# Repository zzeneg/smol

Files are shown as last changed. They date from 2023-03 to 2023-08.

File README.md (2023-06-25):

# Smol

Small and cheap low profile split keyboard with 36 keys using RP2040 Zero microcontrollers.

## Features

- 36 keys
- low profile choc switches with hotswap and choc spacing
- per-key RGB matrix
- Waveshare RP2040 Zero controller
- QMK firmware
- TRRS connection between splits (can use USB-C instead but not recommended, too low for many cables)
- Panasonic EVQWGD001 roller encoder (left side only) or EC11 rotary encoder (both sides)

## Photos

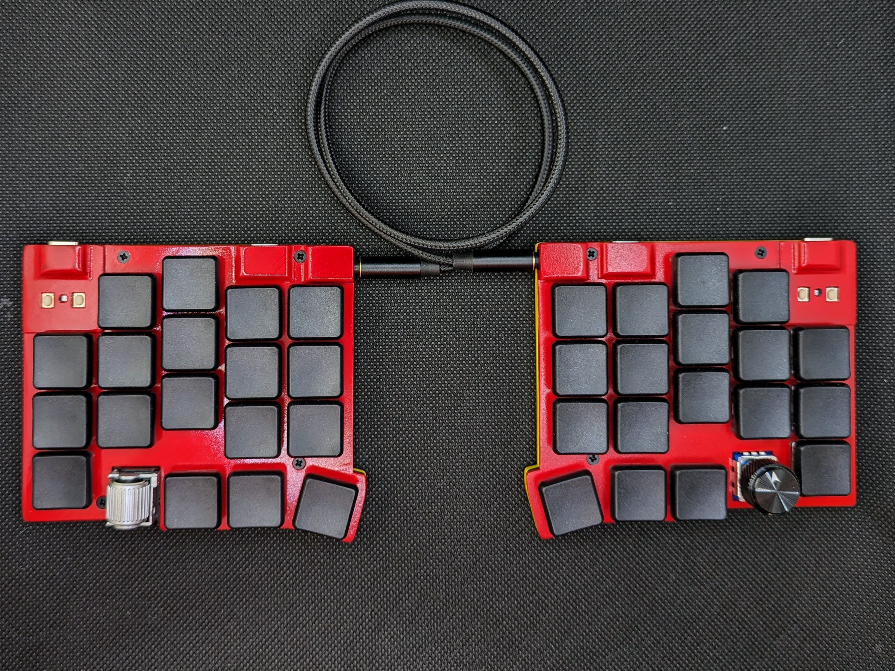
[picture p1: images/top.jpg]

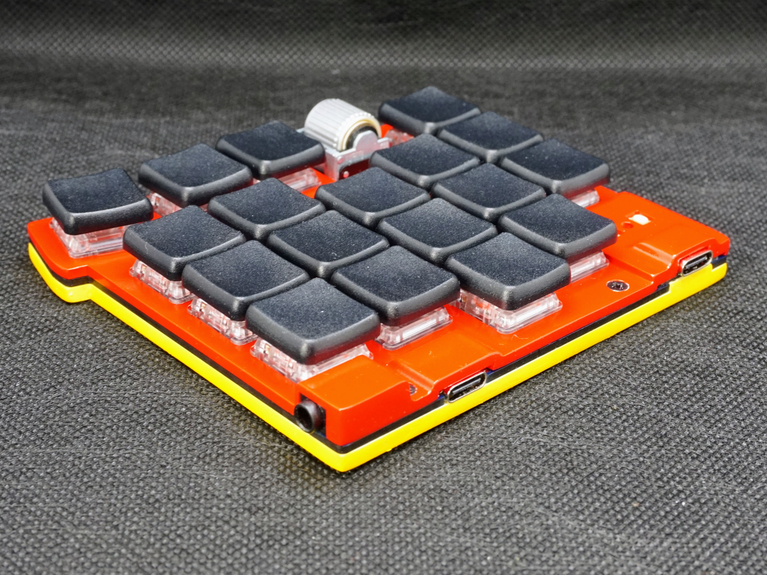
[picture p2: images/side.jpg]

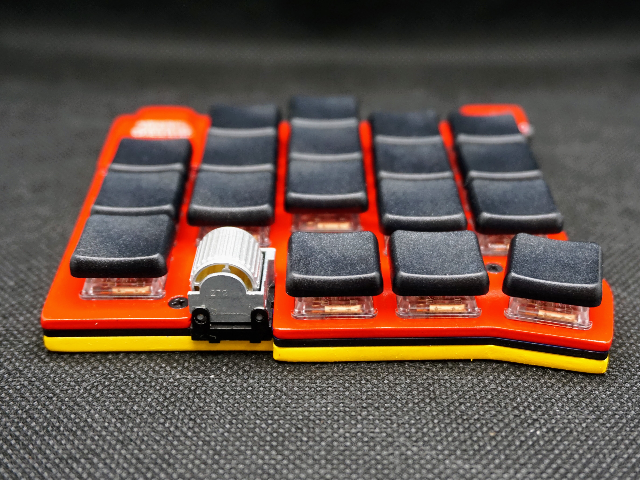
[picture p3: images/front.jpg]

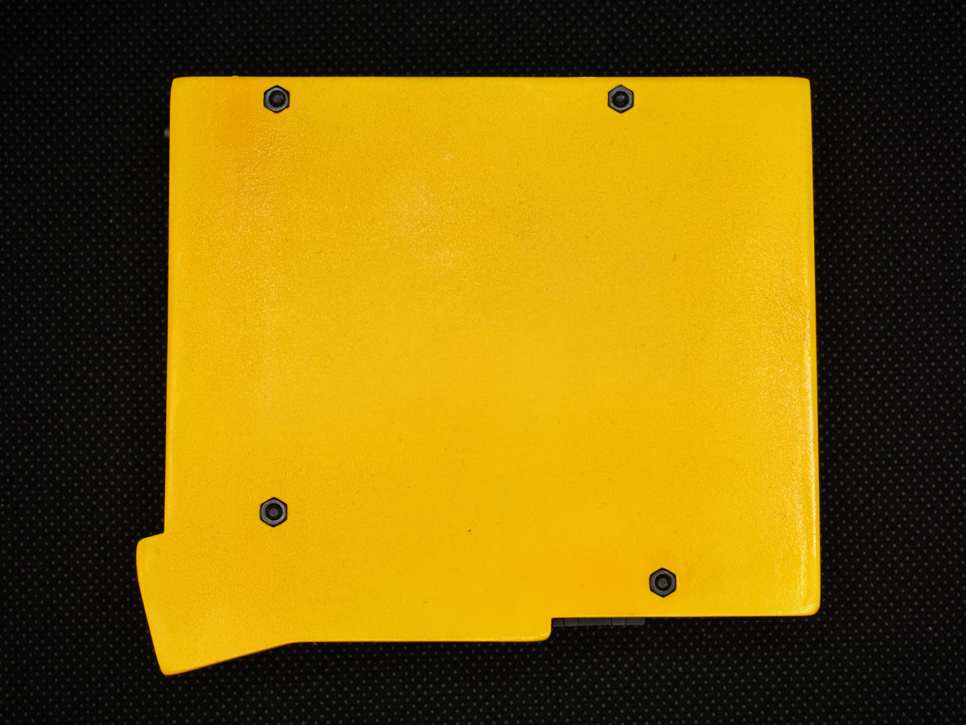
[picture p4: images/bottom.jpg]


## Gerber files

- [PCB](gerbers/pcb.zip)

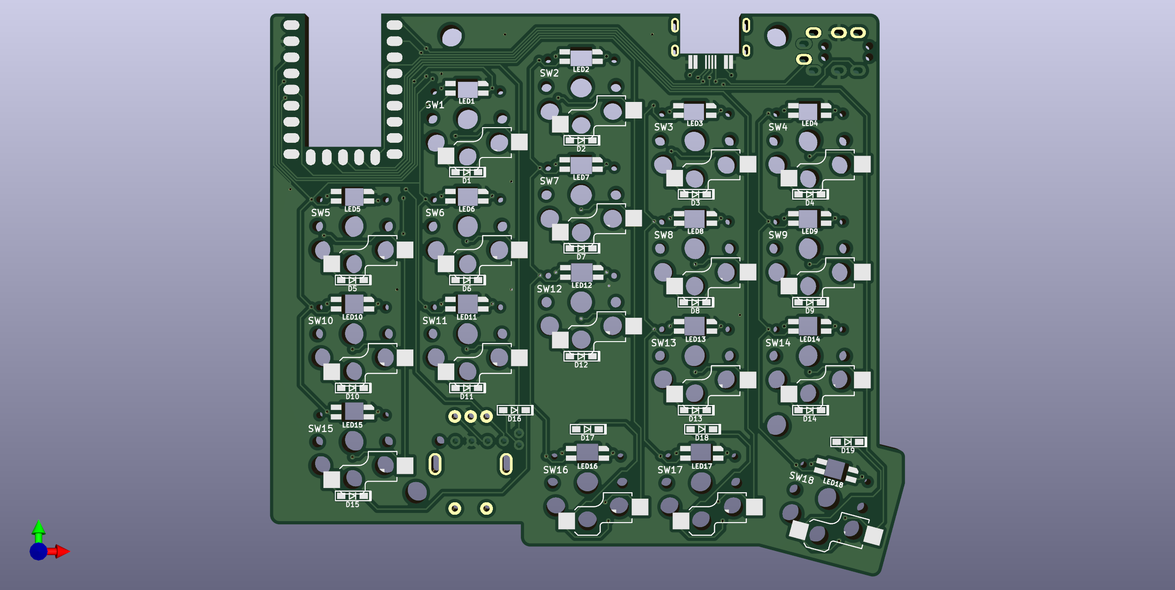
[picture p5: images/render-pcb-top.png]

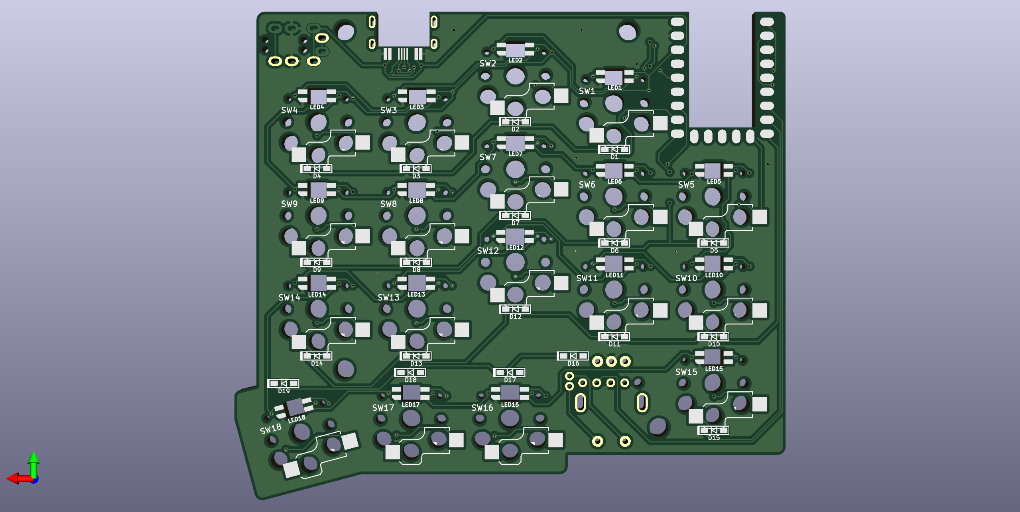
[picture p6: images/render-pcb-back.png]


## Case files

In [STL folder](./stl/) - files for left/right parts. Left also has a version for roller encoder (make sure to order both top and bottom with roller).

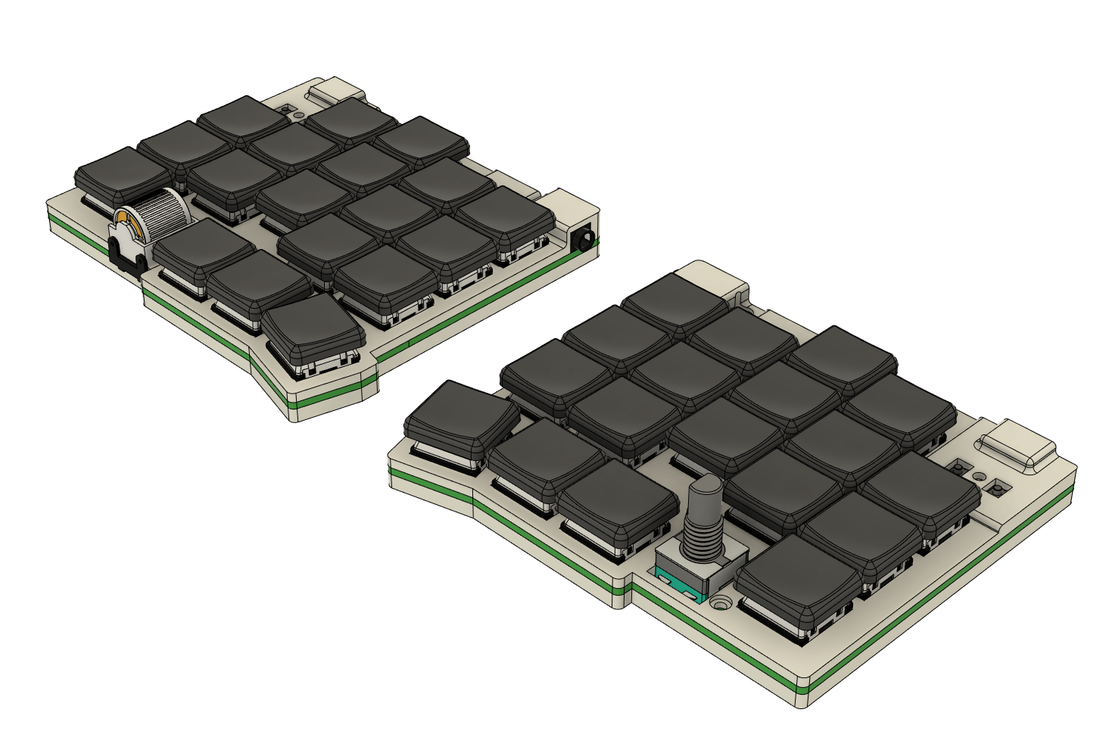
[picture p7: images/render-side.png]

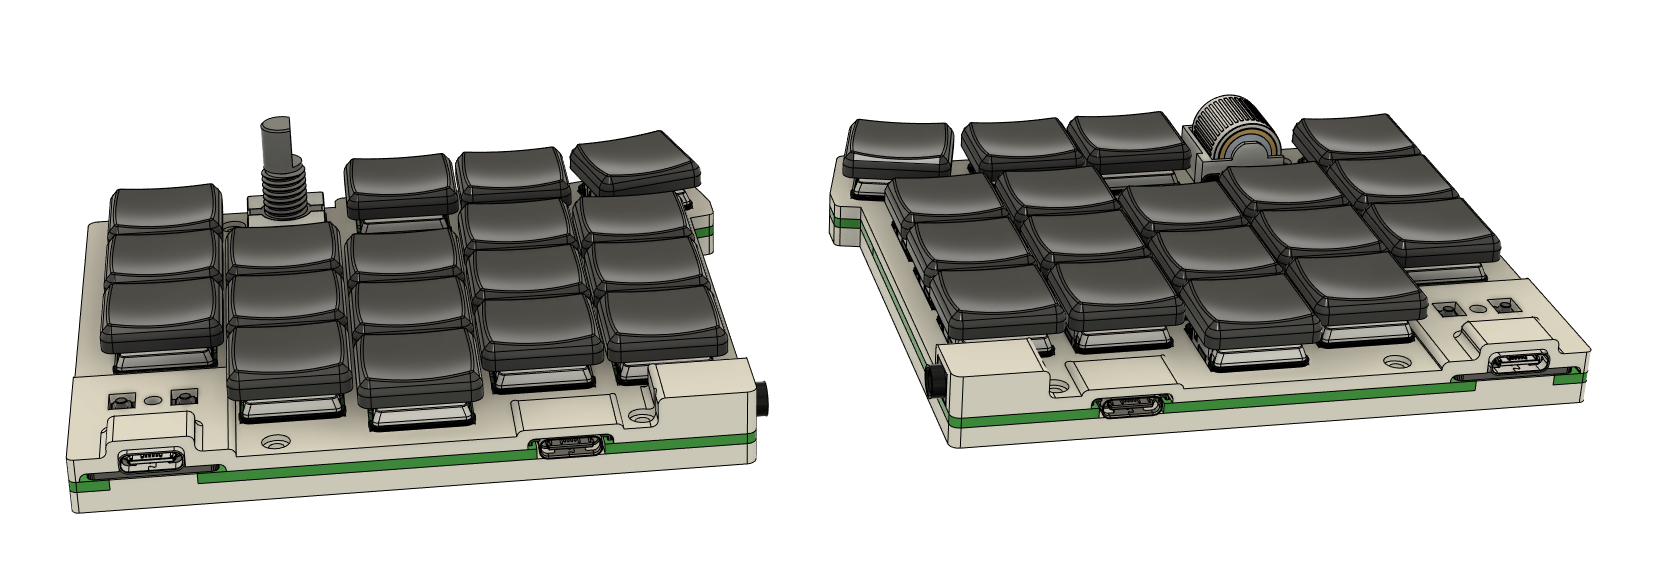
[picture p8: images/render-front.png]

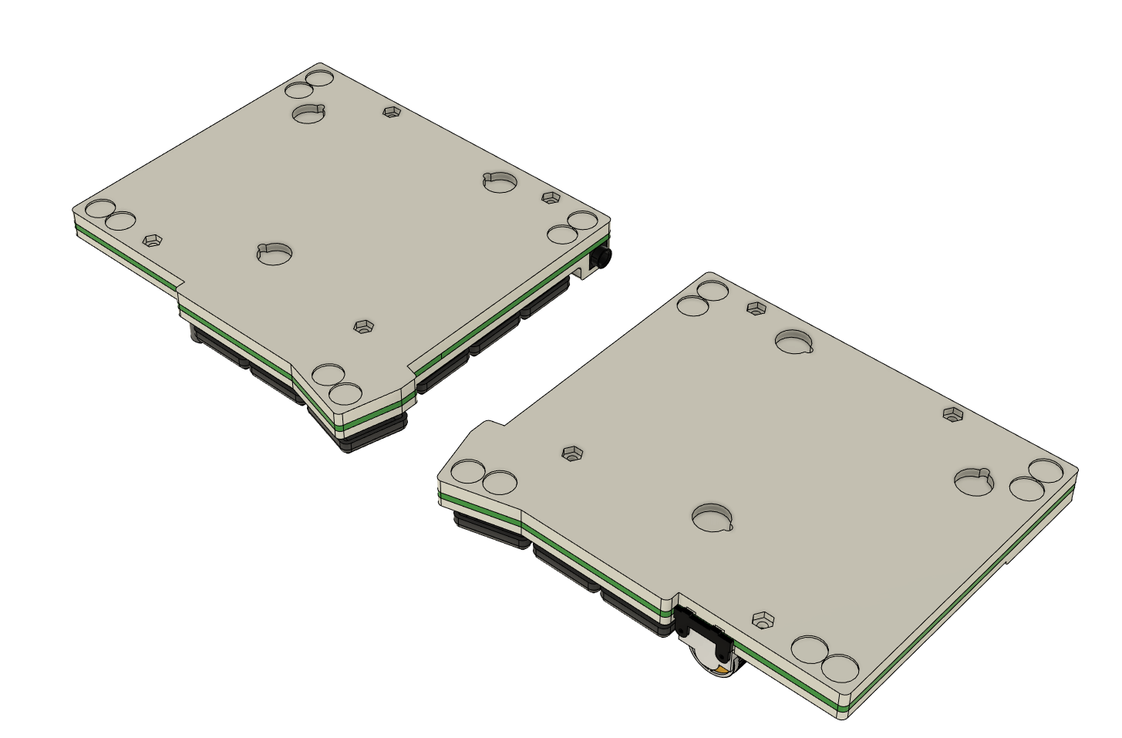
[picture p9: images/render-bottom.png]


## Bill of materials

_Prices for EU with taxes and shipping_

Total cost with required parts: **$42**

- PCBs - $6 (JLCPCB)
- Case (4 parts) - $13 (JLCPCB, white resin)
- 2 Waveshare [RP2040 Zero](https://www.aliexpress.com/item/3256804090654134.html) MCUs - $8.5
- 36 [SMD SOD-123 1N4148](https://www.aliexpress.com/item/1005002882901030.html) diodes - $2
- 1 or 2 [EC11/12 rotary encoder](https://www.aliexpress.com/item/33006686909.html) with [knob](https://www.aliexpress.com/item/1005003425428192.html) - $5
- [Panasonic EVQWGD001 roller encoder](https://www.aliexpress.com/item/32990950196.html) - $9, optional
- 6mm M2 [screws with flat head](https://www.aliexpress.com/item/4001248931159.html) and [nuts](https://www.aliexpress.com/item/1005001412230125.html) - $4
- [TRRS PJ-320A](https://www.aliexpress.com/item/4000661212458.html) connectors - $1.5
- [TRRS cable](https://www.aliexpress.com/item/1005003676559658.html) - $2
- [RGB LEDs](https://www.aliexpress.com/item/1005003636607308.html) - $8.5, optional

## Firmware

QMK:

- [source code](https://github.com/zzeneg/qmk_firmware/tree/feature/smol/keyboards/smol)
- [pre-compiled file](./firmware/qmk/smol_zzeneg.uf2)

Vial:

- [source code](https://github.com/zzeneg/vial-qmk/tree/feature/smol/keyboards/smol)
- [pre-compiled file](./firmware/vial/smol_vial.uf2)

## Changelog

- 2023-06-25 - new case with magnet and feet holes, new Fusion 360 project with design history

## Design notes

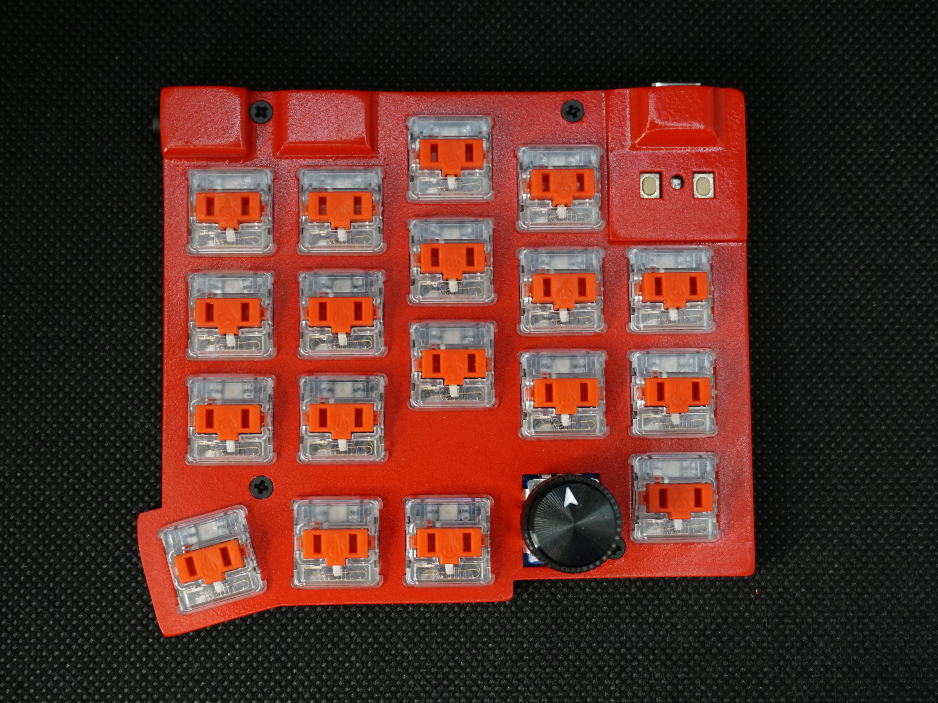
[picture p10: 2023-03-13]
images/naked.jpg

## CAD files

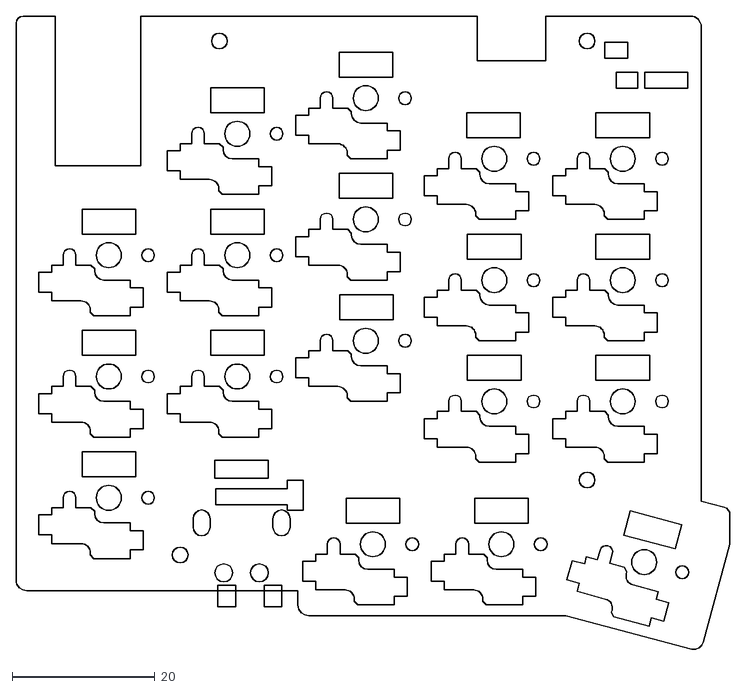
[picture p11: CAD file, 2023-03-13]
case/bottom-left.dxf
100.0 x 88.8

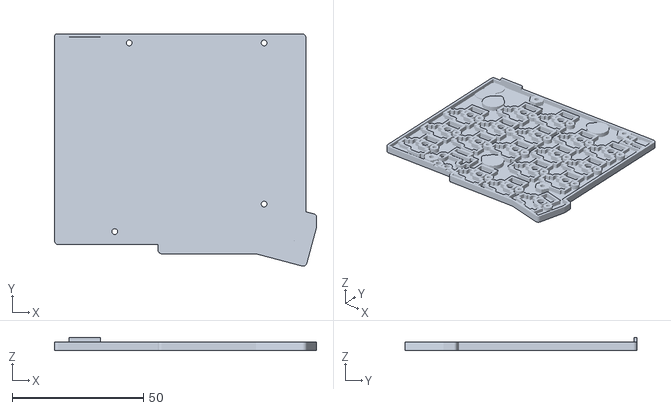
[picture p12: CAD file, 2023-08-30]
stl/bottom_case v14_left-roller.stl
100.0 x 88.7 x 4.80

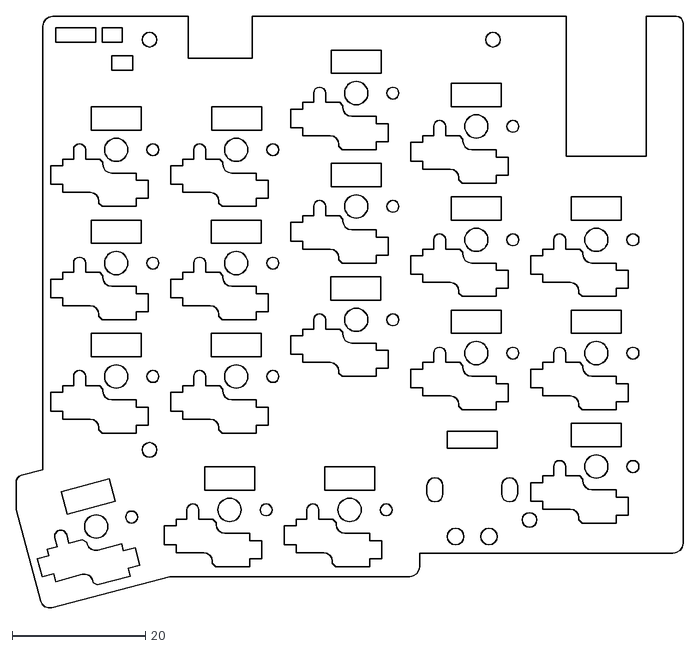
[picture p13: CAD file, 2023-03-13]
case/bottom-right.dxf
100.0 x 88.8

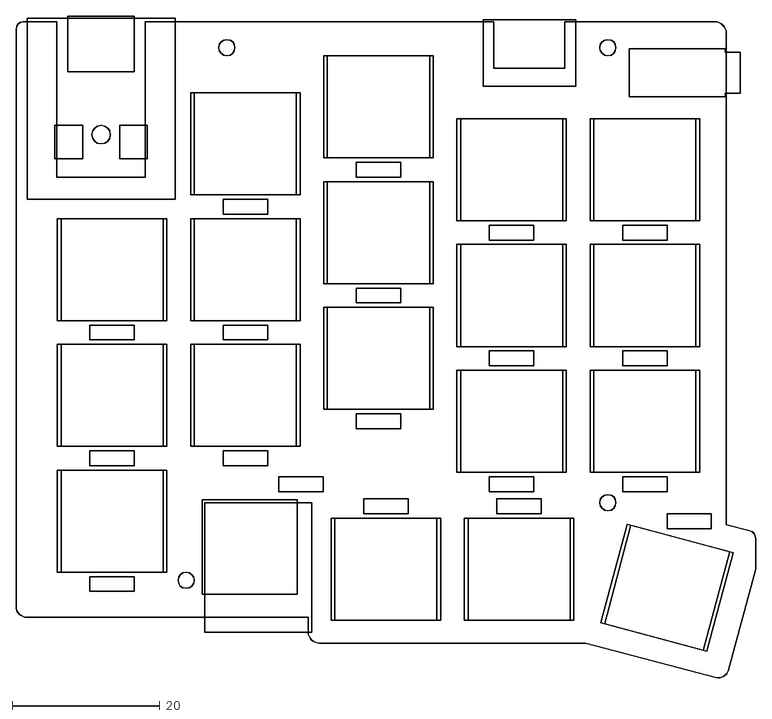
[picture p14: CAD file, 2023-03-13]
case/top-left.dxf
100.0 x 89.6

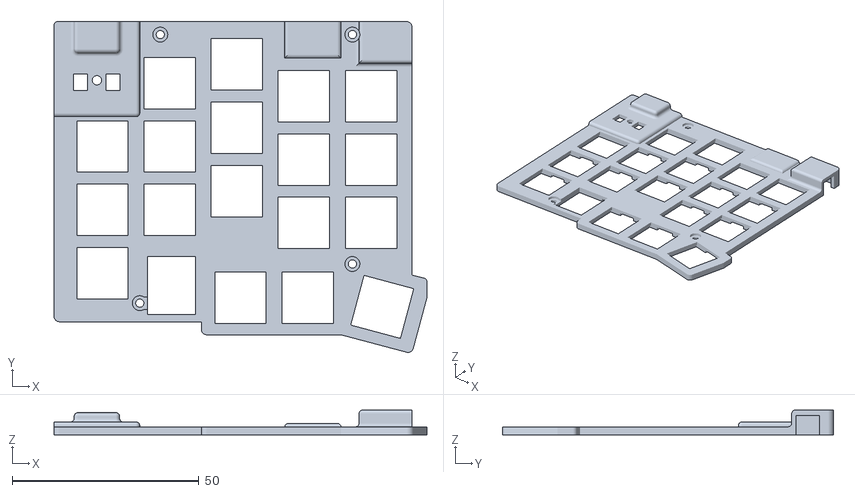
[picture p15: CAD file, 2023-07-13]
stl/top_case v12_left.stl
100.0 x 88.7 x 6.70

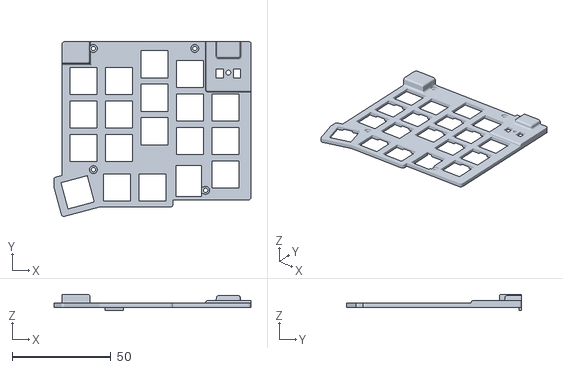
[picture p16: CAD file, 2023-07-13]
stl/top_case v12_right-no-usb.stl
100.0 x 88.7 x 8.30

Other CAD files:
stl/bottom_case v14_left.stl
stl/bottom_case v14_right.stl
stl/top_case v12_right.stl
stl/top_case v12_left-roller-no-usb.stl
stl/top_case v12_left-roller.stl
stl/top_case v12_left-no-usb.stl

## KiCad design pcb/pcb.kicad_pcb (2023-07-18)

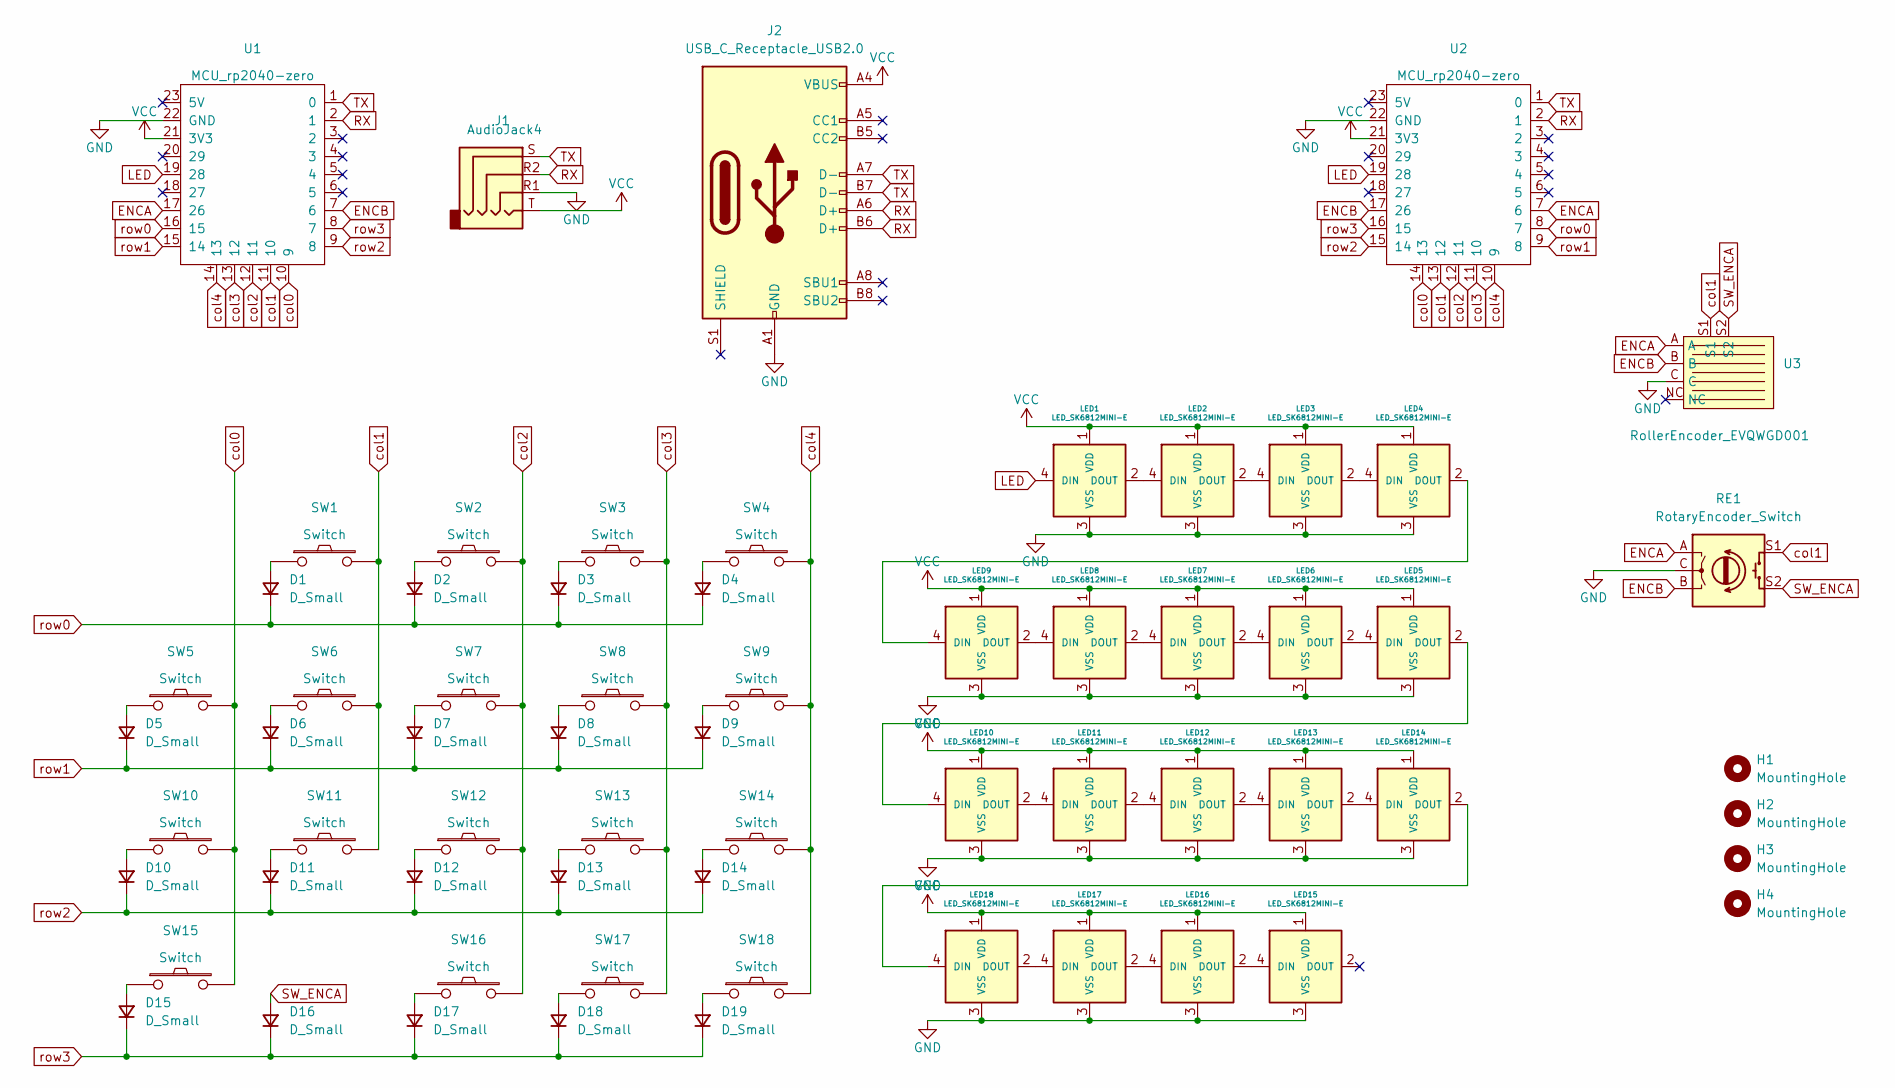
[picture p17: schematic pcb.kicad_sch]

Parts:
D1, D2, D3, D4, D5, D6, D7, D8, D9, D10, D11, D12, D13, D14, D15, D16, D17, D18, D19: D_Small; Diode_1N4148-SOD123-reversible-flip3d
H1, H2, H3, H4: MountingHole; Hole_M2-spacer
J1: AudioJack4; Connector_TRRS-reversible
J2: USB_C_Receptacle_USB2.0; Connector_USB-C-mid-mount-ali-reversible-data
LED1, LED2, LED3, LED4, LED5, LED6, LED7, LED8, LED9, LED10, LED11, LED12, LED13, LED14, LED15, LED16, LED17, LED18: LED_SK6812MINI-E; LED_SK6812-MINI-E-reversible
RE1: RotaryEncoder_Switch; RotaryEncoder_EC11-reversible
SW1, SW2, SW3, SW4, SW5, SW6, SW7, SW8, SW9, SW10, SW11, SW12, SW13, SW14, SW15, SW16, SW17, SW18: Switch; Switch_ChocV1-hotswap-reversible
U1, U2: MCU_rp2040-zero; MCU_rp2040-zero-smd
U3: RollerEncoder_EVQWGD001; RotaryEncoder_EVQWGD001

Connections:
ENCA: RE1.A, U1.17 (26), U2.7 (6), U3.A
ENCB: RE1.B, U1.7 (6), U2.17 (26), U3.B
GND: J1.R1, J2.A1 (GND), J2.A12 (GND), J2.B1 (GND), J2.B12 (GND), LED1.3 (VSS), LED2.3 (VSS), LED3.3 (VSS), LED4.3 (VSS), LED5.3 (VSS), LED6.3 (VSS), LED7.3 (VSS), LED8.3 (VSS), LED9.3 (VSS), LED10.3 (VSS), LED11.3 (VSS), LED12.3 (VSS), LED13.3 (VSS), LED14.3 (VSS), LED15.3 (VSS), LED16.3 (VSS), LED17.3 (VSS), LED18.3 (VSS), RE1.C, U1.22 (GND), U2.22 (GND), U3.C
LED: LED1.4 (DIN), U1.19 (28), U2.19 (28)
unnamed: D1.2 (A), SW1.1
unnamed: D2.2 (A), SW2.1
unnamed: D3.2 (A), SW3.1
unnamed: D4.2 (A), SW4.1
unnamed: D5.2 (A), SW5.1
unnamed: D6.2 (A), SW6.1
unnamed: D7.2 (A), SW7.1
unnamed: D8.2 (A), SW8.1
unnamed: D9.2 (A), SW9.1
unnamed: D10.2 (A), SW10.1
unnamed: D11.2 (A), SW11.1
unnamed: D12.2 (A), SW12.1
unnamed: D13.2 (A), SW13.1
unnamed: D14.2 (A), SW14.1
unnamed: D15.2 (A), SW15.1
unnamed: D17.2 (A), SW16.1
unnamed: D18.2 (A), SW17.1
unnamed: D19.2 (A), SW18.1
unnamed: LED1.2 (DOUT), LED2.4 (DIN)
unnamed: LED2.2 (DOUT), LED3.4 (DIN)
unnamed: LED3.2 (DOUT), LED4.4 (DIN)
unnamed: LED4.2 (DOUT), LED9.4 (DIN)
unnamed: LED5.4 (DIN), LED6.2 (DOUT)
unnamed: LED6.4 (DIN), LED7.2 (DOUT)
unnamed: LED7.4 (DIN), LED8.2 (DOUT)
unnamed: LED8.4 (DIN), LED9.2 (DOUT)
unnamed: LED10.2 (DOUT), LED11.4 (DIN)
unnamed: LED5.2 (DOUT), LED10.4 (DIN)
unnamed: LED11.2 (DOUT), LED12.4 (DIN)
unnamed: LED12.2 (DOUT), LED13.4 (DIN)
unnamed: LED13.2 (DOUT), LED14.4 (DIN)
unnamed: LED14.2 (DOUT), LED18.4 (DIN)
unnamed: LED15.4 (DIN), LED16.2 (DOUT)
unnamed: LED16.4 (DIN), LED17.2 (DOUT)
unnamed: LED17.4 (DIN), LED18.2 (DOUT)
RX: J1.R2, J2.A6 (D+), J2.B6 (D+), U1.2 (1), U2.2 (1)
SW_ENCA: D16.2 (A), RE1.S2, U3.S2
TX: J1.S, J2.A7 (D-), J2.B7 (D-), U1.1 (0), U2.1 (0)
VCC: J1.T, J2.A4 (VBUS), J2.A9 (VBUS), J2.B4 (VBUS), J2.B9 (VBUS), LED1.1 (VDD), LED2.1 (VDD), LED3.1 (VDD), LED4.1 (VDD), LED5.1 (VDD), LED6.1 (VDD), LED7.1 (VDD), LED8.1 (VDD), LED9.1 (VDD), LED10.1 (VDD), LED11.1 (VDD), LED12.1 (VDD), LED13.1 (VDD), LED14.1 (VDD), LED15.1 (VDD), LED16.1 (VDD), LED17.1 (VDD), LED18.1 (VDD), U1.21 (3V3), U2.21 (3V3)
col0: SW5.2, SW10.2, SW15.2, U1.10 (9), U2.14 (13)
col1: RE1.S1, SW1.2, SW6.2, SW11.2, U1.11 (10), U2.13 (12), U3.S1
col2: SW2.2, SW7.2, SW12.2, SW16.2, U1.12 (11), U2.12 (11)
col3: SW3.2, SW8.2, SW13.2, SW17.2, U1.13 (12), U2.11 (10)
col4: SW4.2, SW9.2, SW14.2, SW18.2, U1.14 (13), U2.10 (9)
row0: D1.1 (K), D2.1 (K), D3.1 (K), D4.1 (K), U1.16 (15), U2.8 (7)
row1: D5.1 (K), D6.1 (K), D7.1 (K), D8.1 (K), D9.1 (K), U1.15 (14), U2.9 (8)
row2: D10.1 (K), D11.1 (K), D12.1 (K), D13.1 (K), D14.1 (K), U1.9 (8), U2.15 (14)
row3: D15.1 (K), D16.1 (K), D17.1 (K), D18.1 (K), D19.1 (K), U1.8 (7), U2.16 (15)

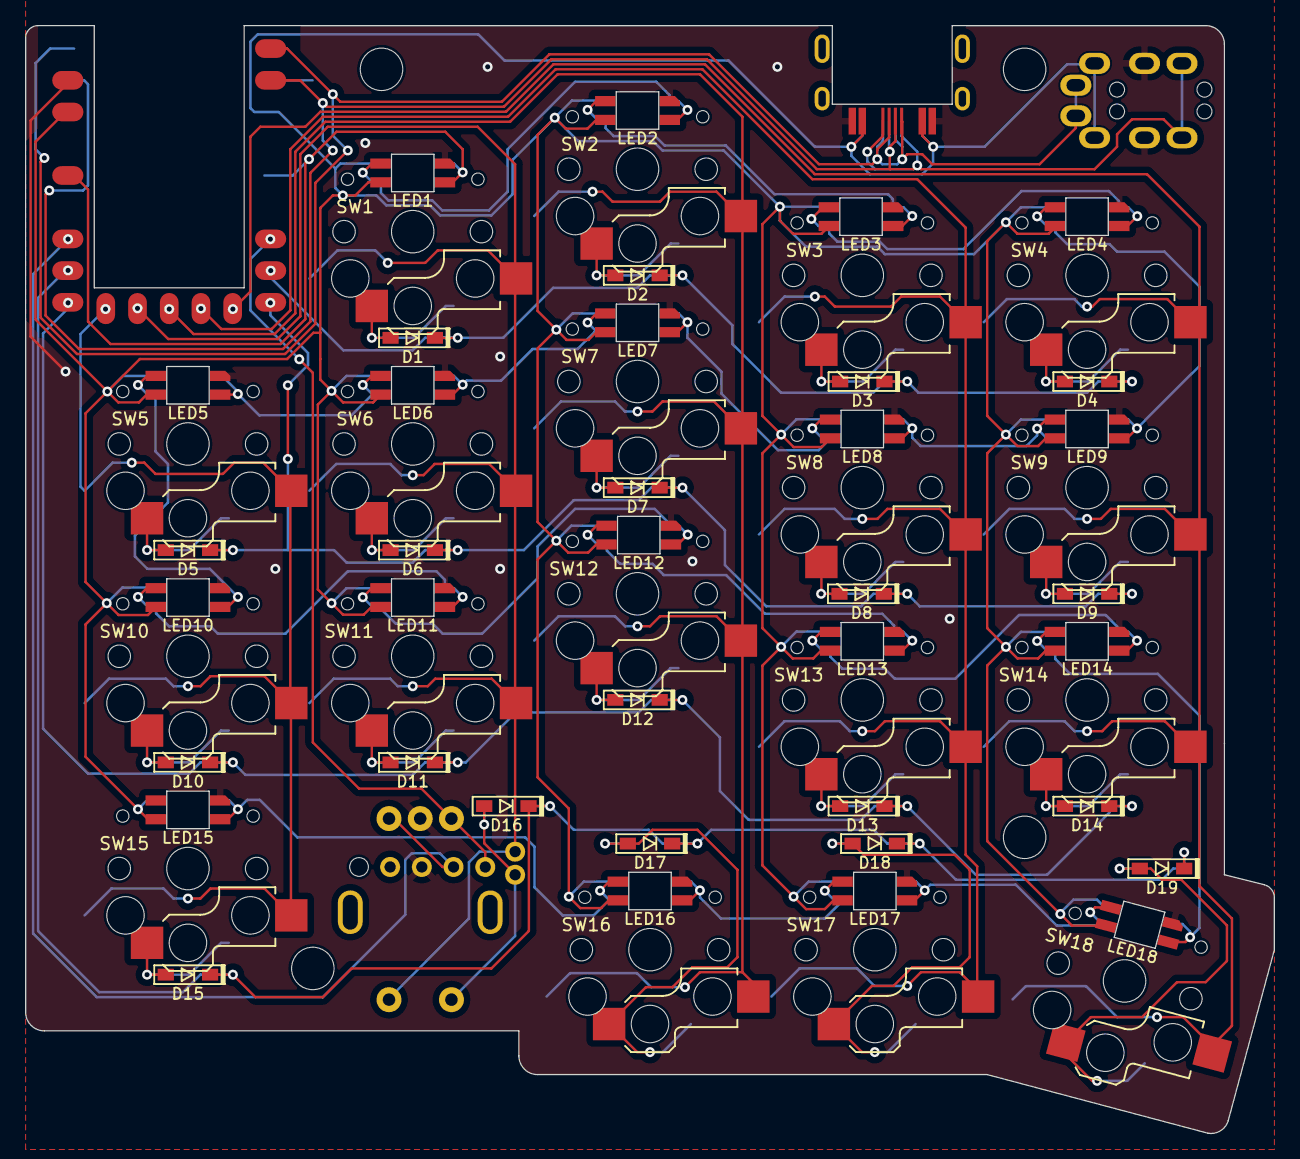
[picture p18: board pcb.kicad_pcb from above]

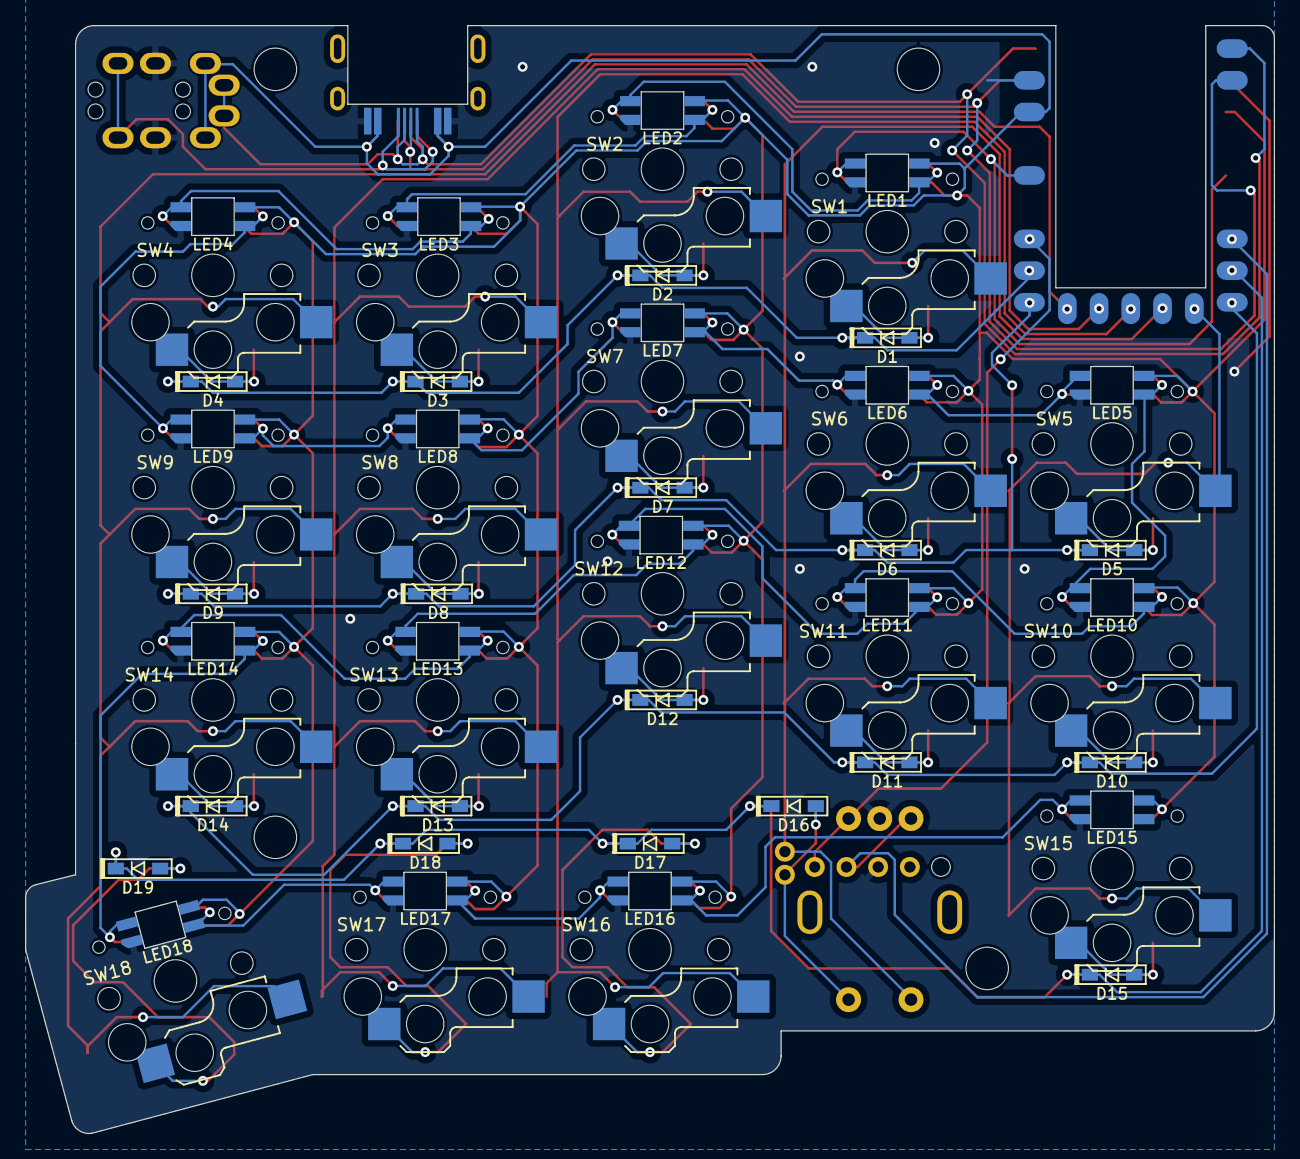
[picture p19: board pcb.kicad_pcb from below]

Board: 2 copper layers, 100.0 x 88.7 mm, 65 parts (20 on the bottom side), 52 nets.

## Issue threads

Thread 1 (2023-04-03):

Roller on both sides?

BigBlueHat, 2023-04-03:
First, thanks for building this design! I'm hoping to build it out for my next board.

Second, I was wondering if there were technical limitations that prevented a roller encoder on both sides, or if the initial design just didn't support it.

In my head, I'd like to have two--one left-to-right and one up-to-down--for page scrolling/mouse-wheel (with modifier).

Just curious if it is conceivably possible or if there's some key limitation that'd be hard to overcome.

Sorry for the newbie question, and thanks again for sharing!

Cheers!
🎩

BigBlueHat, 2023-04-03:
Ah...it's the reversible PCB...

I might just need to make my peace with having a (hopefully low profile) rotary there instead.

Maybe in a non-reversible version 2? 😉

Thanks again for building and sharing this design!

zzeneg, 2023-04-03:
Hey, yes - it's reversible, so I don't think it's possible to make the roller footprint reversible and have enough space for routing.
If you really want it, you could just copy existing PCB, flip that footprint and order two sets of PCBs for left and right sides. But the goal of that board was to be as cheap as possible, and in my mind it's not justified to put two roller encoders on it when even one is more expensive that all PCBs :) I'd say there are more comfortable designs if you can afford to spend more money.

BigBlueHat, 2023-04-03:
Completely agree. 😃

Closed 2023-04-03.

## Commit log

2023-03-12 add pcb
    [pcb.kicad_pcb, pcb.kicad_sch]
2023-03-13 add case
    [bottom-left.dxf, bottom-left.stl, bottom-right.dxf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]
2023-06-25 new case
    [bottom-left.stl, bottom-right.stl, bottom_case v8_left-roller.stl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]
2023-07-03 fix new case
    [bottom_case v8_left-roller.stl, bottom_case v8_left.stl, bottom_case v8_right.stl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]
2023-07-03 small PCB updates
    [pcb.kicad_pcb]
2023-07-13 small case updates
    [bottom_case v12_left-roller.stl, bottom_case v12_left.stl, bottom_case v12_right.stl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]
